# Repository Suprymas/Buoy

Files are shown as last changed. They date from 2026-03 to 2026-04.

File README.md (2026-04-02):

# Buoy system

This repository contains the codebase for the Buoy project, which is designed to monitor environmental conditions and predict upcoming wind shifts. The primary goal is to provide this information to sailing vessels, allowing them to anticipate changes in wind direction and optimize their routes accordingly.

Each buoy is built around the XIAO ESP32S3 platform and integrates several key components. A GPS module is used to determine the precise location of each buoy, enabling accurate mapping and tracking. A compass sensor provides orientation data, allowing the system to infer wind direction based on how the buoy is positioned relative to external forces. Additionally, a wind speed sensor measures real-time wind intensity, giving further context to the environmental conditions.

The ESP32S3’s onboard camera is used to stream a live visual feed from the buoy. This visual data plays an important role in the project’s core idea: analyzing cloud movement to predict wind shifts. By observing the direction and behavior of clouds over time, the system attempts to estimate how wind patterns are likely to change in the near future.

Currently, all collected data is transmitted to a central web server, where it is processed and made accessible through a web application built with React. The application provides a real-time interface for interacting with the system: users can view live camera feeds from each buoy, monitor sensor data streams, and observe buoy positions on a map along with their current orientation. Additionally, a live logging interface displays incoming data from the buoys, allowing for debugging and monitoring.

## Project contents

In the [internal](./internal/) folder you will find the Golang code for the main web server. The purpose of this server is to gather data from multiple buoys. It would host a Web socket server and allow buoys to send that data though it.

In the [esp32](./esp32/) folder you will find [esp_32_boey.ino](./esp32/esp32_boey.ino) which should be uploaded to each buoy. **It is important to change the buoy Id before uploading the code**.

**Device used: [Seeed Studio XIAO ESP32-S3 Sense](https://wiki.seeedstudio.com/xiao_esp32s3_getting_started/)**

In the [frontend](./frontend/) a simple React dashboard to display the latest datas from the Buoys. A map which displays the buoys and the latest images from them.

In [migrations](./migrations/) folder you will find the schema of the **Timescaledb**.

In [3d models](./3d%20models) folder you will find models for 3d printing the physical buoy itself in .STL, .STEP and .SLDPRT formats.

### **WIP:**
In [imageProcessing](./imageProcessing/) folder stuff was started to begin using OpenCV and YOLO to predict the cloud movements. This is yet to be finished. 

## Docker environment

You will find the [Dockerfile](./Dockerfile) meant to create an image for the web server. And also a [docker compose](./docker-compose.yml) file where the required services are configured.

## Start the project

**!!! Important**
> When you have your Esp ready. Change the Wifi and password to connect to your wifi. To run this project properly. The machine running the websocket server and Esp **must** be on the same network. Also don't forget in the Esp code to declare the address of Websocket server!

Clone the repository

Then create an .env file and copy this into it:
```txt
MINIO_ENDPOINT=localhost:9000
MINIO_ACCESS_KEY=admin
MINIO_SECRET_KEY=password123
DB_USER=postgres
DB_PASSWORD=password
DB_HOST=localhost
DB_PORT=5432
DB_NAME=buoydb
```

Build the image:
```sh
docker build -t buoy-image .
```
And then run:
```sh
docker compose up
```

Then you should start turn on the ESP32 and they should connect to the server if they are on the same wifi.
Open http://localhost:5173 and there you should see the working buoy dashboard (Web app).
If you wish to see the images stored open http://localhost:9001.
## Web app

### Dashboard

dashboard

You can see the buoy name, live camera feed, GPS longitude and latitude, satellite count, and compass readings.

### Map

map

You can see a map on which all buoys are placed. The arrow indicates the wind direction of each buoy.

### Logs



You can see the live feed of all data sent from buoys.

## Troubleshooting

### ESP32 is not connecting to server.

Prefer using your phone as a hotspot instead of Eduroam or other more complex networks. When you are sharing from you phone
enable 2.4Ghz and disable Wifi6. The Esp32 wifi capabilities are not that powerfull.
Also check if you changed ssid and the password in [./esp32/esp32_boey.ino](./esp32/esp32_boey.ino) lines 44-45.
Sometimes there could be some problems that Esp32 doesn't connect on first try to the wifi try waiting for few minutes.

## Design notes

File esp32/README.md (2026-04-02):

# ESP32

## Name

Change the BUOY_ID of each buoy so that each one has a unique ID and they do not overlap.

```
static const char* BUOY_ID = "buoy-01";
```

## Wi-Fi hotspot

The ESP32 needs to connect to a Wi-Fi hotspot to send data. To set that up, WIFI_SSID and WIFI_PASSWORD should be changed to the SSID and password of your hotspot.

```
static const char* WIFI_SSID = "*******";
static const char* WIFI_PASSWORD = "*******";
```

## Websocket

The ESP32 sends data to a WebSocket at an IP address defined by WS_HOST. Change that IP address to the address of your WebSocket.

```
static const char* WS_HOST = "10.249.211.51";
```

## Troubleshooting

If the camera does not work (fails to initialize), you need to enable PSRAM in the Arduino IDE (Tools -> PSRAM -> OPI PSRAM).

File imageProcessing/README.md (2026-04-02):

In this folder not much was done. Initial coding was started to track the cloud movements but no more.

If you are starting here your next steps should be to gather some training data with the Esp32 camera and train a model.

Then use "anypoint tracking" method or others to detect the movements of the sky.

In the [camera_calibrate.py](./camera_calibrate.py) file is the code for calibrating the camera of Esp32.

In the [cloudDetectionOpticalFlow.py](./cloudDetectionOpticalFlow.py) was my first try at trying to detect cloud movements.

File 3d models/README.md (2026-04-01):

# 3D models

## Formats

The files are provided in three formats: SLDPRT, STEP and STL.

SLDPRT - Contains SOLIDWORKS .SLDPRT (2025 SP5 version) files. Used to modify the models in SOLIDWORKS.

STEP - Contains .STEP files. Used to slightly modify files with other programs.

STL - Containts .STL files. Used for printing the models.

## Files

body - the main buoy body on which the XIAO ESP32S3 case, GPS, and wind sensor are mounted.

body-bottom - glued to the bottom of the body, houses the 18650 cell casing, and has the bearing inserted into the bottom.

esp-case - houses the XIAO ESP32S3. Has holes for pins, antenna, and USB-C.

esp-case-top - closes the XIAO ESP32S3 into the case, has a hole for the camera, and a special place to glue the lens on.

handle - used to attach the whole thing to the pole.

## Example

example

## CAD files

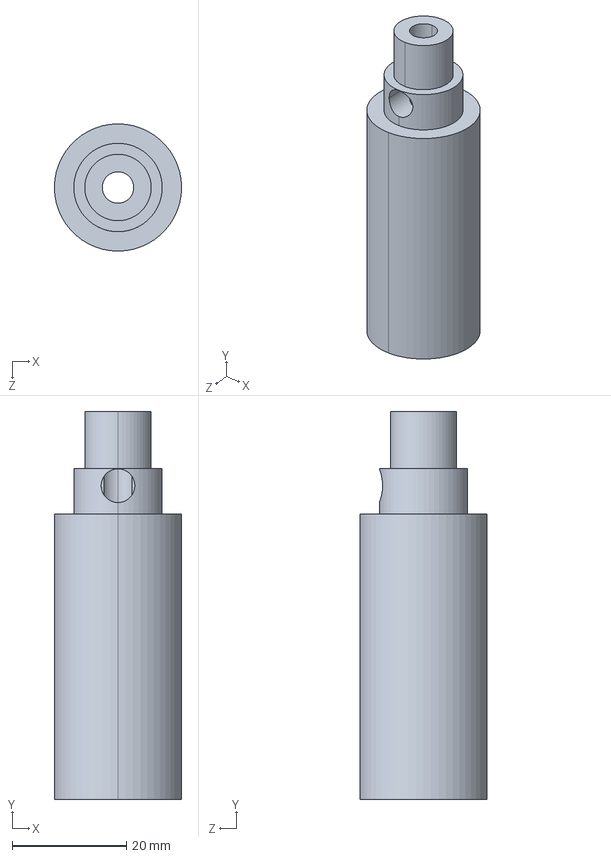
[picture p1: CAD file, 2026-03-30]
3d models/STEP/handle.STEP
22.3 x 68.0 x 22.3 mm

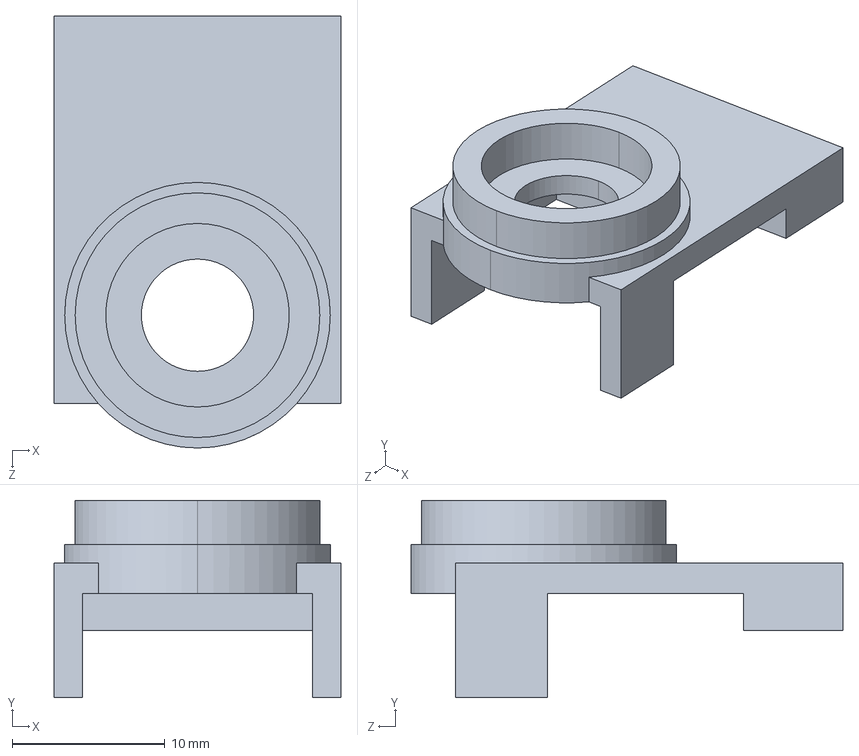
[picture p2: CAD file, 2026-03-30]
3d models/STEP/esp-case-top.STEP
18.7 x 12.9 x 28.3 mm

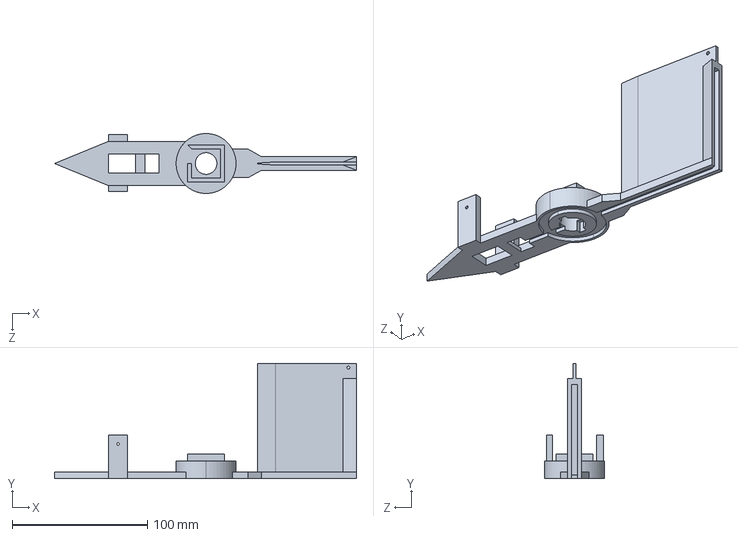
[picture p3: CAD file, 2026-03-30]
3d models/STEP/body.STEP
223.2 x 85.0 x 44.3 mm

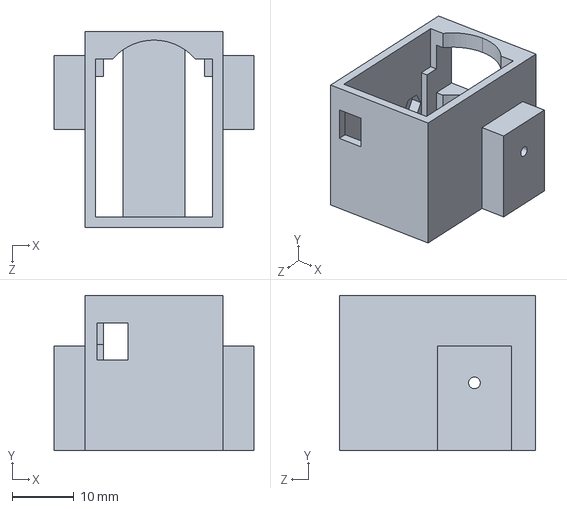
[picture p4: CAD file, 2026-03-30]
3d models/STEP/esp-case.STEP
32.5 x 25.2 x 31.9 mm

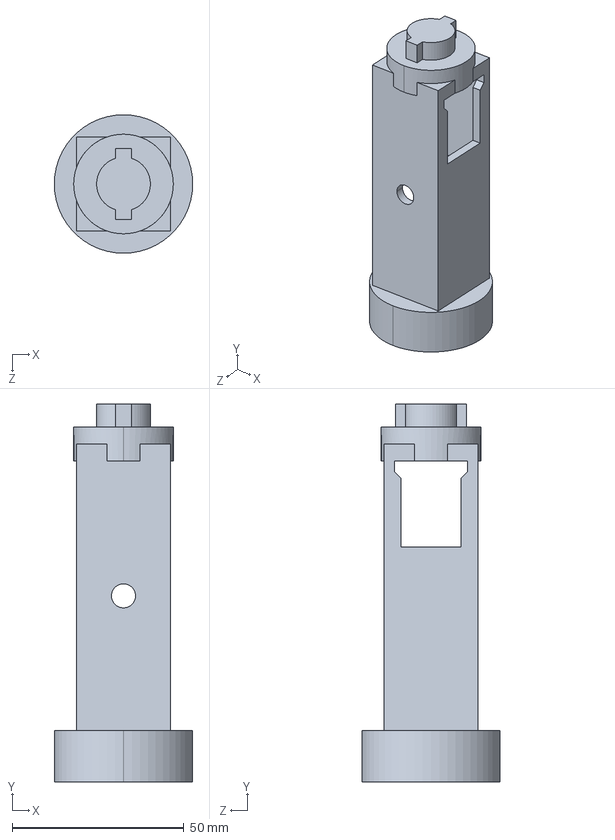
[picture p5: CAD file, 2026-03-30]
3d models/STEP/body-bottom.STEP
40.3 x 110.0 x 40.3 mm

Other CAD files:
3d models/SLDPRT/body-bottom.SLDPRT
3d models/SLDPRT/body.SLDPRT
3d models/SLDPRT/esp-case-top.SLDPRT
3d models/SLDPRT/esp-case.SLDPRT
3d models/SLDPRT/handle.SLDPRT
3d models/STL/body-bottom.STL
3d models/STL/body.STL
3d models/STL/esp-case-top.STL
3d models/STL/esp-case.STL
3d models/STL/handle.STL

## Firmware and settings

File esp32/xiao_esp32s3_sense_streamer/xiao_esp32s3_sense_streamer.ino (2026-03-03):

#include <WiFi.h>
#include <WebSocketsClient.h>
#include "esp_camera.h"
#include "mbedtls/base64.h"

// XIAO ESP32S3 Sense camera pin map based on Seeed examples for CAMERA_MODEL_XIAO_ESP32S3.
#define PWDN_GPIO_NUM   -1
#define RESET_GPIO_NUM  -1
#define XCLK_GPIO_NUM   10
#define SIOD_GPIO_NUM   40
#define SIOC_GPIO_NUM   39

#define Y9_GPIO_NUM     48
#define Y8_GPIO_NUM     11
#define Y7_GPIO_NUM     12
#define Y6_GPIO_NUM     14
#define Y5_GPIO_NUM     16
#define Y4_GPIO_NUM     18
#define Y3_GPIO_NUM     17
#define Y2_GPIO_NUM     15
#define VSYNC_GPIO_NUM  38
#define HREF_GPIO_NUM   47
#define PCLK_GPIO_NUM   13

static const char* WIFI_SSID = "YOUR_WIFI_SSID";
static const char* WIFI_PASSWORD = "YOUR_WIFI_PASSWORD";

static const char* WS_HOST = "192.168.1.100";
static const uint16_t WS_PORT = 8080;
static const char* WS_PATH = "/ws";

static const char* BUOY_ID = "boey-01";

static const unsigned long IMAGE_INTERVAL_MS = 1000;
static const unsigned long TELEMETRY_INTERVAL_MS = 200;

WebSocketsClient webSocket;
unsigned long lastImageAt = 0;
unsigned long lastTelemetryAt = 0;

bool initCamera();
void connectWifi();
void connectWebSocket();
void onWebSocketEvent(WStype_t type, uint8_t* payload, size_t length);
void sendFrame();
void sendTelemetry();
String buildFrameJson(const String& imageBase64);
String buildTelemetryJson();
String base64Encode(const uint8_t* data, size_t len);
String fakeGps();
String fakeCompass();

void setup() {
  Serial.begin(115200);
  delay(1000);

  if (!initCamera()) {
    Serial.println("Camera initialization failed");
    while (true) {
      delay(1000);
    }
  }

  connectWifi();
  connectWebSocket();
}

void loop() {
  webSocket.loop();

  if (WiFi.status() != WL_CONNECTED) {
    connectWifi();
  }

  const unsigned long now = millis();

  if (webSocket.isConnected() && now - lastTelemetryAt >= TELEMETRY_INTERVAL_MS) {
    lastTelemetryAt = now;
    sendTelemetry();
  }

  if (webSocket.isConnected() && now - lastImageAt >= IMAGE_INTERVAL_MS) {
    lastImageAt = now;
    sendFrame();
  }
}

bool initCamera() {
  camera_config_t config;
  config.ledc_channel = LEDC_CHANNEL_0;
  config.ledc_timer = LEDC_TIMER_0;
  config.pin_d0 = Y2_GPIO_NUM;
  config.pin_d1 = Y3_GPIO_NUM;
  config.pin_d2 = Y4_GPIO_NUM;
  config.pin_d3 = Y5_GPIO_NUM;
  config.pin_d4 = Y6_GPIO_NUM;
  config.pin_d5 = Y7_GPIO_NUM;
  config.pin_d6 = Y8_GPIO_NUM;
  config.pin_d7 = Y9_GPIO_NUM;
  config.pin_xclk = XCLK_GPIO_NUM;
  config.pin_pclk = PCLK_GPIO_NUM;
  config.pin_vsync = VSYNC_GPIO_NUM;
  config.pin_href = HREF_GPIO_NUM;
  config.pin_sccb_sda = SIOD_GPIO_NUM;
  config.pin_sccb_scl = SIOC_GPIO_NUM;
  config.pin_pwdn = PWDN_GPIO_NUM;
  config.pin_reset = RESET_GPIO_NUM;
  config.xclk_freq_hz = 20000000;
  config.pixel_format = PIXFORMAT_JPEG;
  config.grab_mode = CAMERA_GRAB_LATEST;
  config.fb_location = CAMERA_FB_IN_PSRAM;

  if (psramFound()) {
    config.frame_size = FRAMESIZE_QVGA;
    config.jpeg_quality = 18;
    config.fb_count = 2;
  } else {
    config.frame_size = FRAMESIZE_QQVGA;
    config.jpeg_quality = 20;
    config.fb_count = 1;
    config.fb_location = CAMERA_FB_IN_DRAM;
  }

  esp_err_t err = esp_camera_init(&config);
  if (err != ESP_OK) {
    Serial.printf("esp_camera_init failed: 0x%x\n", err);
    return false;
  }

  sensor_t* sensor = esp_camera_sensor_get();
  if (sensor != nullptr) {
    sensor->set_brightness(sensor, 0);
    sensor->set_saturation(sensor, 0);
    sensor->set_contrast(sensor, 0);
  }

  return true;
}

void connectWifi() {
  if (WiFi.status() == WL_CONNECTED) {
    return;
  }

  Serial.printf("Connecting to Wi-Fi SSID: %s\n", WIFI_SSID);
  WiFi.mode(WIFI_STA);
  WiFi.begin(WIFI_SSID, WIFI_PASSWORD);

  while (WiFi.status() != WL_CONNECTED) {
    delay(500);
    Serial.print(".");
  }

  Serial.println();
  Serial.print("Wi-Fi connected, IP: ");
  Serial.println(WiFi.localIP());
}

void connectWebSocket() {
  webSocket.begin(WS_HOST, WS_PORT, WS_PATH);
  webSocket.setReconnectInterval(3000);
  webSocket.enableHeartbeat(15000, 3000, 2);
  webSocket.onEvent(onWebSocketEvent);
}

void onWebSocketEvent(WStype_t type, uint8_t* payload, size_t length) {
  switch (type) {
    case WStype_CONNECTED:
      Serial.printf("WebSocket connected to ws://%s:%u%s\n", WS_HOST, WS_PORT, WS_PATH);
      break;
    case WStype_DISCONNECTED:
      Serial.println("WebSocket disconnected");
      break;
    case WStype_TEXT:
      Serial.printf("Server text: %.*s\n", static_cast<int>(length), payload);
      break;
    case WStype_ERROR:
      Serial.println("WebSocket error");
      break;
    default:
      break;
  }
}

void sendFrame() {
  camera_fb_t* frame = esp_camera_fb_get();
  if (frame == nullptr) {
    Serial.println("Failed to capture frame");
    return;
  }

  String imageBase64 = base64Encode(frame->buf, frame->len);
  esp_camera_fb_return(frame);

  if (imageBase64.length() == 0) {
    Serial.println("Failed to encode frame");
    return;
  }

  String payload = buildFrameJson(imageBase64);
  bool ok = webSocket.sendTXT(payload);
  Serial.printf("Frame sent: %s, payload bytes=%u\n", ok ? "ok" : "failed", payload.length());
}

void sendTelemetry() {
  String payload = buildTelemetryJson();
  webSocket.sendTXT(payload);
}

String buildFrameJson(const String& imageBase64) {
  String json;
  json.reserve(imageBase64.length() + 192);
  json += "{\"buoyId\":\"";
  json += BUOY_ID;
  json += "\",\"status\":\"online\",\"gps\":\"";
  json += fakeGps();
  json += "\",\"compass\":\"";
  json += fakeCompass();
  json += "\",\"imageBase64\":\"";
  json += imageBase64;
  json += "\"}";
  return json;
}

String buildTelemetryJson() {
  String json;
  json.reserve(160);
  json += "{\"buoyId\":\"";
  json += BUOY_ID;
  json += "\",\"status\":\"online\",\"gps\":\"";
  json += fakeGps();
  json += "\",\"compass\":\"";
  json += fakeCompass();
  json += "\"}";
  return json;
}

String base64Encode(const uint8_t* data, size_t len) {
  size_t encodedLen = 0;
  int rc = mbedtls_base64_encode(nullptr, 0, &encodedLen, data, len);
  if (rc != MBEDTLS_ERR_BASE64_BUFFER_TOO_SMALL || encodedLen == 0) {
    return "";
  }

  unsigned char* buffer = static_cast<unsigned char*>(ps_malloc(encodedLen + 1));
  if (buffer == nullptr) {
    return "";
  }

  rc = mbedtls_base64_encode(buffer, encodedLen, &encodedLen, data, len);
  if (rc != 0) {
    free(buffer);
    return "";
  }

  buffer[encodedLen] = '\0';
  String out(reinterpret_cast<char*>(buffer));
  free(buffer);
  return out;
}

String fakeGps() {
  // Replace this with real GPS sensor input when available.
  return "54.6872,25.2797";
}

String fakeCompass() {
  // Replace this with a real compass sensor reading when available.
  return "182";
}

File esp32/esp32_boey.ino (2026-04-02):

#include <WiFi.h>
#include <WebSocketsClient.h>
#include "esp_camera.h"
#include <Wire.h>
#include <TinyGPS++.h>
#include <QMC5883LCompass.h>
/* ================= CAMERA PINS ================= */

#define PWDN_GPIO_NUM   -1
#define RESET_GPIO_NUM  -1
#define XCLK_GPIO_NUM   10
#define SIOD_GPIO_NUM   40
#define SIOC_GPIO_NUM   39

#define Y9_GPIO_NUM     48
#define Y8_GPIO_NUM     11
#define Y7_GPIO_NUM     12
#define Y6_GPIO_NUM     14
#define Y5_GPIO_NUM     16
#define Y4_GPIO_NUM     18
#define Y3_GPIO_NUM     17
#define Y2_GPIO_NUM     15
#define VSYNC_GPIO_NUM  38
#define HREF_GPIO_NUM   47
#define PCLK_GPIO_NUM   13

/* ================= COMPASS ================= */

#define COMPASS_ADDR 0x1E
#define SDA_PIN 5
#define SCL_PIN 6
QMC5883LCompass compass;


/* ================= GPS ================= */

#define GPS_RX 44
#define GPS_TX 43

HardwareSerial GPS(1);
TinyGPSPlus gps;
/* ================= WIFI ================= */

static const char* WIFI_SSID = "*******";
static const char* WIFI_PASSWORD = "*******";

/* ================= WEBSOCKET ================= */

static const char* WS_HOST = "10.249.211.51";
static const uint16_t WS_PORT = 8080;
static const char* WS_PATH = "/ws";

/* ================= DEVICE ================= */

static const char* BUOY_ID = "buoy-01";

/* ================= TIMING ================= */

static const unsigned long IMAGE_INTERVAL_MS = 2000;
static const unsigned long TELEMETRY_INTERVAL_MS = 1000;
static const unsigned long WS_CONNECT_INTERVAL_MS = 5000;

/* ================= GLOBALS ================= */

WebSocketsClient webSocket;

unsigned long lastImageAt = 0;
unsigned long lastTelemetryAt = 0;
unsigned long lastWebSocketConnectAttemptAt = 0;

/* GPS DATA */

float gpsLat = 0;
float gpsLon = 0;
String gpsSats = "0";

/* ================= FUNCTIONS ================= */

bool initCamera();
void connectWifi();
void connectWebSocket();
void onWebSocketEvent(WStype_t type, uint8_t* payload, size_t length);

void sendFrame();
void sendTelemetry();

String buildTelemetryJson();
String readCompass();

void readGPS();
void parseGPS(String line);
float nmeaToDecimal(String raw, String dir);

/* ================= SETUP ================= */

void setup() {

  Serial.begin(115200);
  delay(1000);

  Serial.println("System starting");

  Serial.print("PSRAM: ");
  Serial.println(psramFound());

  /* QMC5883 
     Used HGLRC M100 compass, Make sure to calibrate it.
  */
  compass.init();
  compass.setCalibrationOffsets(-65.00, 560.00, -7.00);
  compass.setCalibrationScales(1.00, 1.02, 0.98);
  Serial.println("Compass started");

  /* GPS UART */

  GPS.begin(115200, SERIAL_8N1, GPS_RX, GPS_TX);
  Serial.println("GPS started");

  if (!initCamera()) {
    Serial.println("Camera init failed");
    while (true) delay(1000);
  }

  connectWifi();
  connectWebSocket();
}

/* ================= LOOP ================= */

void loop() {
  webSocket.loop();
  readGPS();

  unsigned long now = millis();

  if (WiFi.status() != WL_CONNECTED)
    connectWifi();

  if (!webSocket.isConnected() &&
      WiFi.status() == WL_CONNECTED &&
      now - lastWebSocketConnectAttemptAt >= WS_CONNECT_INTERVAL_MS)
      connectWebSocket();

  if (webSocket.isConnected() &&
      now - lastTelemetryAt >= TELEMETRY_INTERVAL_MS) {

    lastTelemetryAt = now;
    sendTelemetry();
  }

  if (webSocket.isConnected() &&
      now - lastImageAt >= IMAGE_INTERVAL_MS) {

    lastImageAt = now;
    sendFrame();
  }
}

/* ================= CAMERA ================= */

bool initCamera() {

  camera_config_t config = {};

  config.ledc_channel = LEDC_CHANNEL_0;
  config.ledc_timer = LEDC_TIMER_0;

  config.pin_d0 = Y2_GPIO_NUM;
  config.pin_d1 = Y3_GPIO_NUM;
  config.pin_d2 = Y4_GPIO_NUM;
  config.pin_d3 = Y5_GPIO_NUM;
  config.pin_d4 = Y6_GPIO_NUM;
  config.pin_d5 = Y7_GPIO_NUM;
  config.pin_d6 = Y8_GPIO_NUM;
  config.pin_d7 = Y9_GPIO_NUM;

  config.pin_xclk = XCLK_GPIO_NUM;
  config.pin_pclk = PCLK_GPIO_NUM;
  config.pin_vsync = VSYNC_GPIO_NUM;
  config.pin_href = HREF_GPIO_NUM;

  config.pin_sccb_sda = SIOD_GPIO_NUM;
  config.pin_sccb_scl = SIOC_GPIO_NUM;

  config.pin_pwdn = PWDN_GPIO_NUM;
  config.pin_reset = RESET_GPIO_NUM;

  config.xclk_freq_hz = 20000000;
  config.pixel_format = PIXFORMAT_JPEG;

  config.grab_mode = CAMERA_GRAB_LATEST;
  config.fb_location = CAMERA_FB_IN_PSRAM;

  config.frame_size = FRAMESIZE_VGA;
  config.jpeg_quality = 12;
  config.fb_count = 1;

  esp_err_t err = esp_camera_init(&config);

  if (err != ESP_OK) {
    Serial.printf("Camera init error: 0x%x\n", err);
    return false;
  }

  Serial.println("Camera started");
  return true;
}

/* ================= WIFI ================= */

void connectWifi() {

  if (WiFi.status() == WL_CONNECTED) return;

  Serial.printf("Connecting to WiFi: %s\n", WIFI_SSID);

  WiFi.mode(WIFI_STA);
  WiFi.begin(WIFI_SSID, WIFI_PASSWORD);

  unsigned long start = millis();

  while (WiFi.status() != WL_CONNECTED &&
         millis() - start < 10000) {

    delay(500);
    Serial.print(".");
  }

  Serial.println();

  if (WiFi.status() == WL_CONNECTED) {

    Serial.print("WiFi connected. IP: ");
    Serial.println(WiFi.localIP());
  }
}

/* ================= WEBSOCKET ================= */

void connectWebSocket() {

  lastWebSocketConnectAttemptAt = millis();

  Serial.printf("Connecting WS: ws://%s:%u%s\n",
                WS_HOST, WS_PORT, WS_PATH);

  webSocket.begin(WS_HOST, WS_PORT, WS_PATH);
  webSocket.onEvent(onWebSocketEvent);
  webSocket.setReconnectInterval(3000);
}

/* ================= WEBSOCKET EVENTS ================= */

void onWebSocketEvent(WStype_t type,
                      uint8_t* payload,
                      size_t length) {

  if (type == WStype_CONNECTED)
    Serial.println("WebSocket connected");

  if (type == WStype_DISCONNECTED)
    Serial.println("WebSocket disconnected");
}

/* ================= CAMERA FRAME ================= */

void sendFrame() {

  camera_fb_t* frame = esp_camera_fb_get();

  if (!frame) {
    Serial.println("Camera capture failed");
    return;
  }

  webSocket.sendBIN(frame->buf, frame->len);

  esp_camera_fb_return(frame);
}

/* ================= TELEMETRY ================= */

void sendTelemetry() {

  String payload = buildTelemetryJson();

  webSocket.sendTXT(payload);

  Serial.println(payload);
}

/* ================= TELEMETRY JSON ================= */

String buildTelemetryJson() {

  String json;

  json += "{\"type\":\"telemetry\",\"buoyId\":\"";
  json += BUOY_ID;
  json += "\",\"gps\":\"";
  json += String(gpsLat,6);
  json += ",";
  json += String(gpsLon,6);
  json += "\",\"sats\":\"";
  json += gpsSats;
  json += "\",\"compass\":\"";
  json += readCompass();
  json += "\"}";

  return json;
}

/* ================= COMPASS ================= */

String readCompass() {
	compass.read();
	
	int a = compass.getAzimuth();
	int flippedAzimuth = 360 - a;
  if (flippedAzimuth >= 360) flippedAzimuth -= 360;

  return String(flippedAzimuth);
}
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

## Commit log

2026-03-03 esp32 code
2026-03-03 arduino code
2026-03-05 esp32 kodas ir pakeitimai kad sats veiktu
    Took 11 minutes
2026-03-16 Camera calibration, training data collection script
2026-03-30 3d model files added
    [body-bottom.SLDPRT, body-bottom.STEP, body-bottom.STL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]
2026-04-01 esp32 readme
